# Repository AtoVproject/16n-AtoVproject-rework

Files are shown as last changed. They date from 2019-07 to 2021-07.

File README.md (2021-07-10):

<h1>16n AtoVproject Rework</h1>

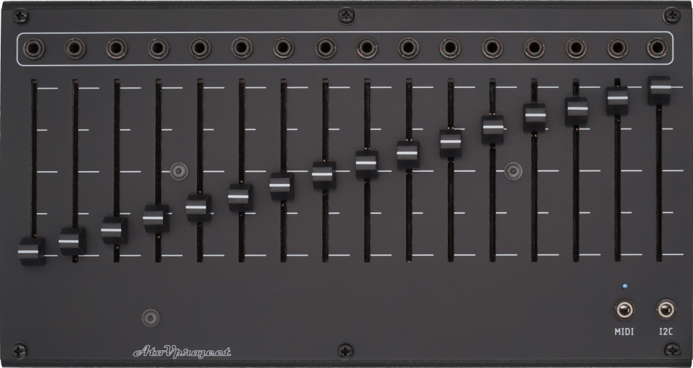
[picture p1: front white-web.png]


Product page: https://atovproject.de/products/16nrework

Manual: https://atovproject.de/manuals/16nrework

This is an hardware modified version of the original 16n. https://github.com/16n-faderbank/16n

Fully assembled unit with high end aluminium enclosure, high end faders and set of cables available @ https://schneidersladen.de/de/atovproject-16n-atovproject-rework

Bourns compatible PCBs Panels and cases are available @ https://pushermanproductions.com/product/16n-euro-version-pcb-and-anodized-aluminium-black-panel/

BOM in the PCB folder

Please download the firmware from the original project https://github.com/16n-faderbank/16n/wiki/Firmware:-installation-instructions

<h2>The concept</h2>

The 16n Faderbank is aimed a solving a problem very specific to modular synthesis. As a patch is getting more and more complex a forest of cables has grown over your system before you know it. The 16n allows you to take the control from the modular into a very ergonomic controller that integrates perfectly into a modern studio.

The 16n is a faderbank sending CV, I2C, MIDI jack compatible with all standards, USB MIDI (compatible PC, Mac, iPad etc...) , making it the absolute ultimate controller for any of your hardware and software all in one! 

This unit was redesigned for a DIY workshop organised in the Berlin Modular community. The redesign was done following the wishes and desires of the community. The 16n AtoVproject redesign is the result of this initiative. 

https://www.youtube.com/watch?v=edriUxDgTsg

<h2>Modifications compared to the original are :</h2>

-Updated power section
  Isolated USB power supply. Proper voltage reference. Upgraded filtering.
    This greatly reduce the noise on the outputs. (Measured at less than 6mV)

-Selectable 5v or 10V outputs: Each can be configured to output either 10V or 5V using a dip switch on the back of the module (even when using 5V USB power supply)

-Outputs facing upwards: The outputs will be directly on the front panel reducing the footprint and making outputs much more accessible.

-Eurorack compatible: You would be able to mount the 16n as a 50hp module in your rack and power it from your own power supply. (+12V=42mA, -12V=0mA)

-The footprint of the jack is compatible for banana connectors! So you'll be able to use it with your Serge or Buchla system.

-I2C connector on the PCB to simplify connection to modules like the ER301

-Two versions of the board are available one with high quality ALPS faders and another one with Bourns mid range faders (1/3 of the price of the ALPS).

<h2>Credits</h2>

Based on original open source work by Brian Crabtree, Sean Hellfritsch, Tom Armitage and Brendon Cassidy. Circuit design update by AtoVproject aka Arthur Gibert

As stated by the original designers the original 16n folows a CC-BY-SA licence therefore the 16n AtoVproject is and will always remain entirely open source following the same licence.

If you are making modification to this design, you must correctly credit everyone involved in the initial version, and also share your own changes with the similar license. So you can’t make a fork of 16n or the 16n AtoVproject redesign that you don’t open-source yourself.

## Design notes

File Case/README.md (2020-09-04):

<h1>Case</h1>

These are files you can send to you laser cutting services (Ponoko, Modulor etc...) to make a case for your Berlin Modular Edition 16n faderbank

I can also cut one for you! Send me an email at info@atovproject.de !

Two version of the case design are available for 3 or 4mm materials. 
This case will work with the 22mm standoffs included in the mouser carts

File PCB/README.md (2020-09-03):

<h1>Gerbers and eagle design files</h1>

Two versions of the board are available. One for high end ALPS faders (which are expensive and quite often out of stock) and another for lower cost Brouns faders (1/3 of the price and more readily available)

The PCB available at https://pushermanproductions.com/product/16n-euro-version-pcb-and-anodized-aluminium-black-panel/ is compatible only with the Brouns faders. 

<h2>Mouser Carts :</h2>

These are complete carts to have all the parts to make the build. They are valid for the latest revision of the boards (v1.4)
Resistors and capacitors are very small so I stronly recommand ordering more (little tip: order resistors and capacitors amounts to the next price break this will make you save a few cents)

Bourns Version
https://www.mouser.com/ProjectManager/ProjectDetail.aspx?AccessID=e279897c7f

ALPS Version
https://www.mouser.com/ProjectManager/ProjectDetail.aspx?AccessID=69297ae739

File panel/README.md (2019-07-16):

<h1>Panel</h1>

The eagle file is a blank template with all the holes and cutouts for the faders and jacks etc... Feel free to create your own design with it

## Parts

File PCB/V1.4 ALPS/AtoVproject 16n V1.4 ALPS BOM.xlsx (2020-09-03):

Qty | Value | Device | Package | Parts | Description | Mouser Number | Note
RESISTOR
2 | 47 | R-EU_R0805 | R0805 | R83, R85 | RESISTOR, European symbol | 603-RT0603FRE0747RL
16 | 1K | R-EU_R0805 | R0805 | R1, R2, R3, R4, R5, R6, R7, R8, R9, R10, R11, R12, R13, R14, R15, R16 | RESISTOR, European symbol | 603-RT0603FRE071KL
32 | 10K | R-EU_R0805 | R0805 | R17, R18, R19, R20, R21, R22, R23, R24, R25, R26, R27, R28, R29, R30, R31, R32, R52, R54, R56, R58, R60, R62, R64, R66, R68, R70, R72, R74, R76, R78, R80, R82 | RESISTOR, European symbol | 603-RT0603FRE0710KL
16 | 10K* | R-EU_R0805 | R0805 | R33, R34, R35, R36, R37, R38, R39, R40, R41, R42, R43, R44, R45, R46, R47, R48 | RESISTOR, European symbol | 603-RT0603FRE0710KL | Can be changed to modify alternative output (eg 10k => 5V, 1.1k => 1V.) Use his formula for desired output R=(100000)/(10-Vout) or use this tool http://www.ohmslawcalculator.com/voltage-divider-calculator
1 | 10k | R-EU_R0805 | R0805 | R84 | RESISTOR, European symbol | 603-RT0603FRE0710KL | Modify to change LED brightness
16 | 20K | R-EU_R0805 | R0805 | R51, R53, R55, R57, R59, R61, R63, R65, R67, R69, R71, R73, R75, R77, R79, R81 | RESISTOR, European symbol | 603-RT0603FRE1320KL
2 | DNP | R-EU_R0805 | R0805 | R49, R50 | RESISTOR, European symbol | 603-RT0603FRE074K7L | Has to be changed to 4.7k to use with ER301
16 | SLIDER | SLIDERS | SLIDEPOT-75 | U$1, U$2, U$3, U$4, U$5, U$6, U$7, U$8, U$9, U$10, U$11, U$12, U$13, U$14, U$15, U$16 | ALPS | 688-RS6011SP6003 | tested with 10k-Value shouldn't matter
CAPACITORS
1 | 10n | C-EUC0805 | C0805 | C3 | CAPACITOR, European symbol | 810-CGA3E2X7R1H103K
9 | 100n | C-EUC0805 | C0805 | C4, C5, C6, C7, C8, C9, C10, C11, C12 | CAPACITOR, European symbol | 810-CGA3E2X7R1H104K
1 | 1u | C-EUC0805 | C0805 | C2 | CAPACITOR, European symbol | 810-CGA3E1X7R1C105AC
1 | 10u | C-EUC0805 | C0805 | C1 | CAPACITOR, European symbol | 810-C1608X6S0G106M
2 | 47uf | CPOL-EUE2.5-6 | E2,5-6 | C100, C101 | POLARIZED CAPACITOR, European symbol | 80-ESS476M025AE2EA | Through hole part Use low profile cap
Diodes - Careful these are polarised
2 | 1N5819W-7-F | DIODE-SOD123 | SOD123 | D1, D6 | DIODE | 621-1N5819HW-F | Reverse voltage protection when using Eurorack power
4 | 1N4148W-7-F | DIODESOD123 | SOD-123 | D2, D3, D4, D5 |  | 621-1N4148W-F | Not needed if not using I2C
1 | LED | LED | LED3MM | LED1 |  | 604-WP710A10SRC/E | Indicate power on state
Ics
4 | MCP6004_SMD | MCP6004_SMD | SO14 | IC5, IC6, IC7, IC8 | Generic Quad Op Amp | 579-MCP6004T-I/SL | Has to be rail to rail op amp
4 | NCS2007 | NCS2007 | SO14 | IC1, IC2, IC3, IC4 |  | 863-NCS20074DR2G | Has to be rail to rail op amp
1 | CD74HC4067SM96 | 744067SO24 | SOIC127P1030X265-24 | IC9 | 16-channel analog MUX | 595-CD74HC4067M
Voltage regulators
1 | DC-ISO | DC-ISO | TMA | V100 | DC/DC Converter TME Series 1 Watt | 709-SPU01L-12 | Converts 5V USB to 12V
1 | EURO_POWER_HEADERREGULAR | EURO_POWER_HEADERREGULAR | EURO_POWER_HEADER | SV100 | Power Header
1 | LM1117 | LM1117 5V | SOT223 | V2 | 5V regulator | 926-LM1117IMPX50NOPB
1 | LP2985 | LP2985 10V | SOT23-5 | V1 | 10V regulator | 595-LP2985-10DBVR
Misc
16 | THONKICONN | THONKICONN | WQP-PJ301M-12JACK-BANANA | J1, J2, J3, J4, J5, J6, J7, J8, J9, J10, J11, J12, J13, J14, J15, J16 | 3.5mm socket for Eurorack modular synths |  | Order at Thonk, Modular Addict, Synthcube etc...
2 | THONKI-STEREO | THONKI-STEREO | WQP-PJ366ST_JACK | JP1, JP2 | 3.5mm socket for Eurorack modular synths |  | Order at Thonk, Modular Addict, Synthcube etc...
2 | 8 position DIP switch | 8 position DIP switch | 8 position DIP switch | S1, S2 |  | 774-2198MST
2 |  | SWITCH-DPDTEG2211 | EG2211 | S100, S101 | Switch | 612-EG2211
1 | TEENSY_3.2_PIN | TEENSY_3.2_PIN | TEENSY_3_AND_LC_SERIES_BOARDS_V1.4_TEENSY_3.0-3.2&LC_DIL | IC10 | Teensy 3.1 or 3.2 in a DIL Layout. | 474-DEV-13736 (https://www.mouser.de/ProductDetail/474-DEV-13736)
 |  |  |  | Standoff 10mm |  | 710-970100321
 |  |  |  | Standoff 22mm |  | 710-970220361
12 |  |  |  | M3 screw
6 |  |  |  | M3 countersunk screw
1 | 40 pin Headers to cu to size |  |  |  |  | 571-41037410

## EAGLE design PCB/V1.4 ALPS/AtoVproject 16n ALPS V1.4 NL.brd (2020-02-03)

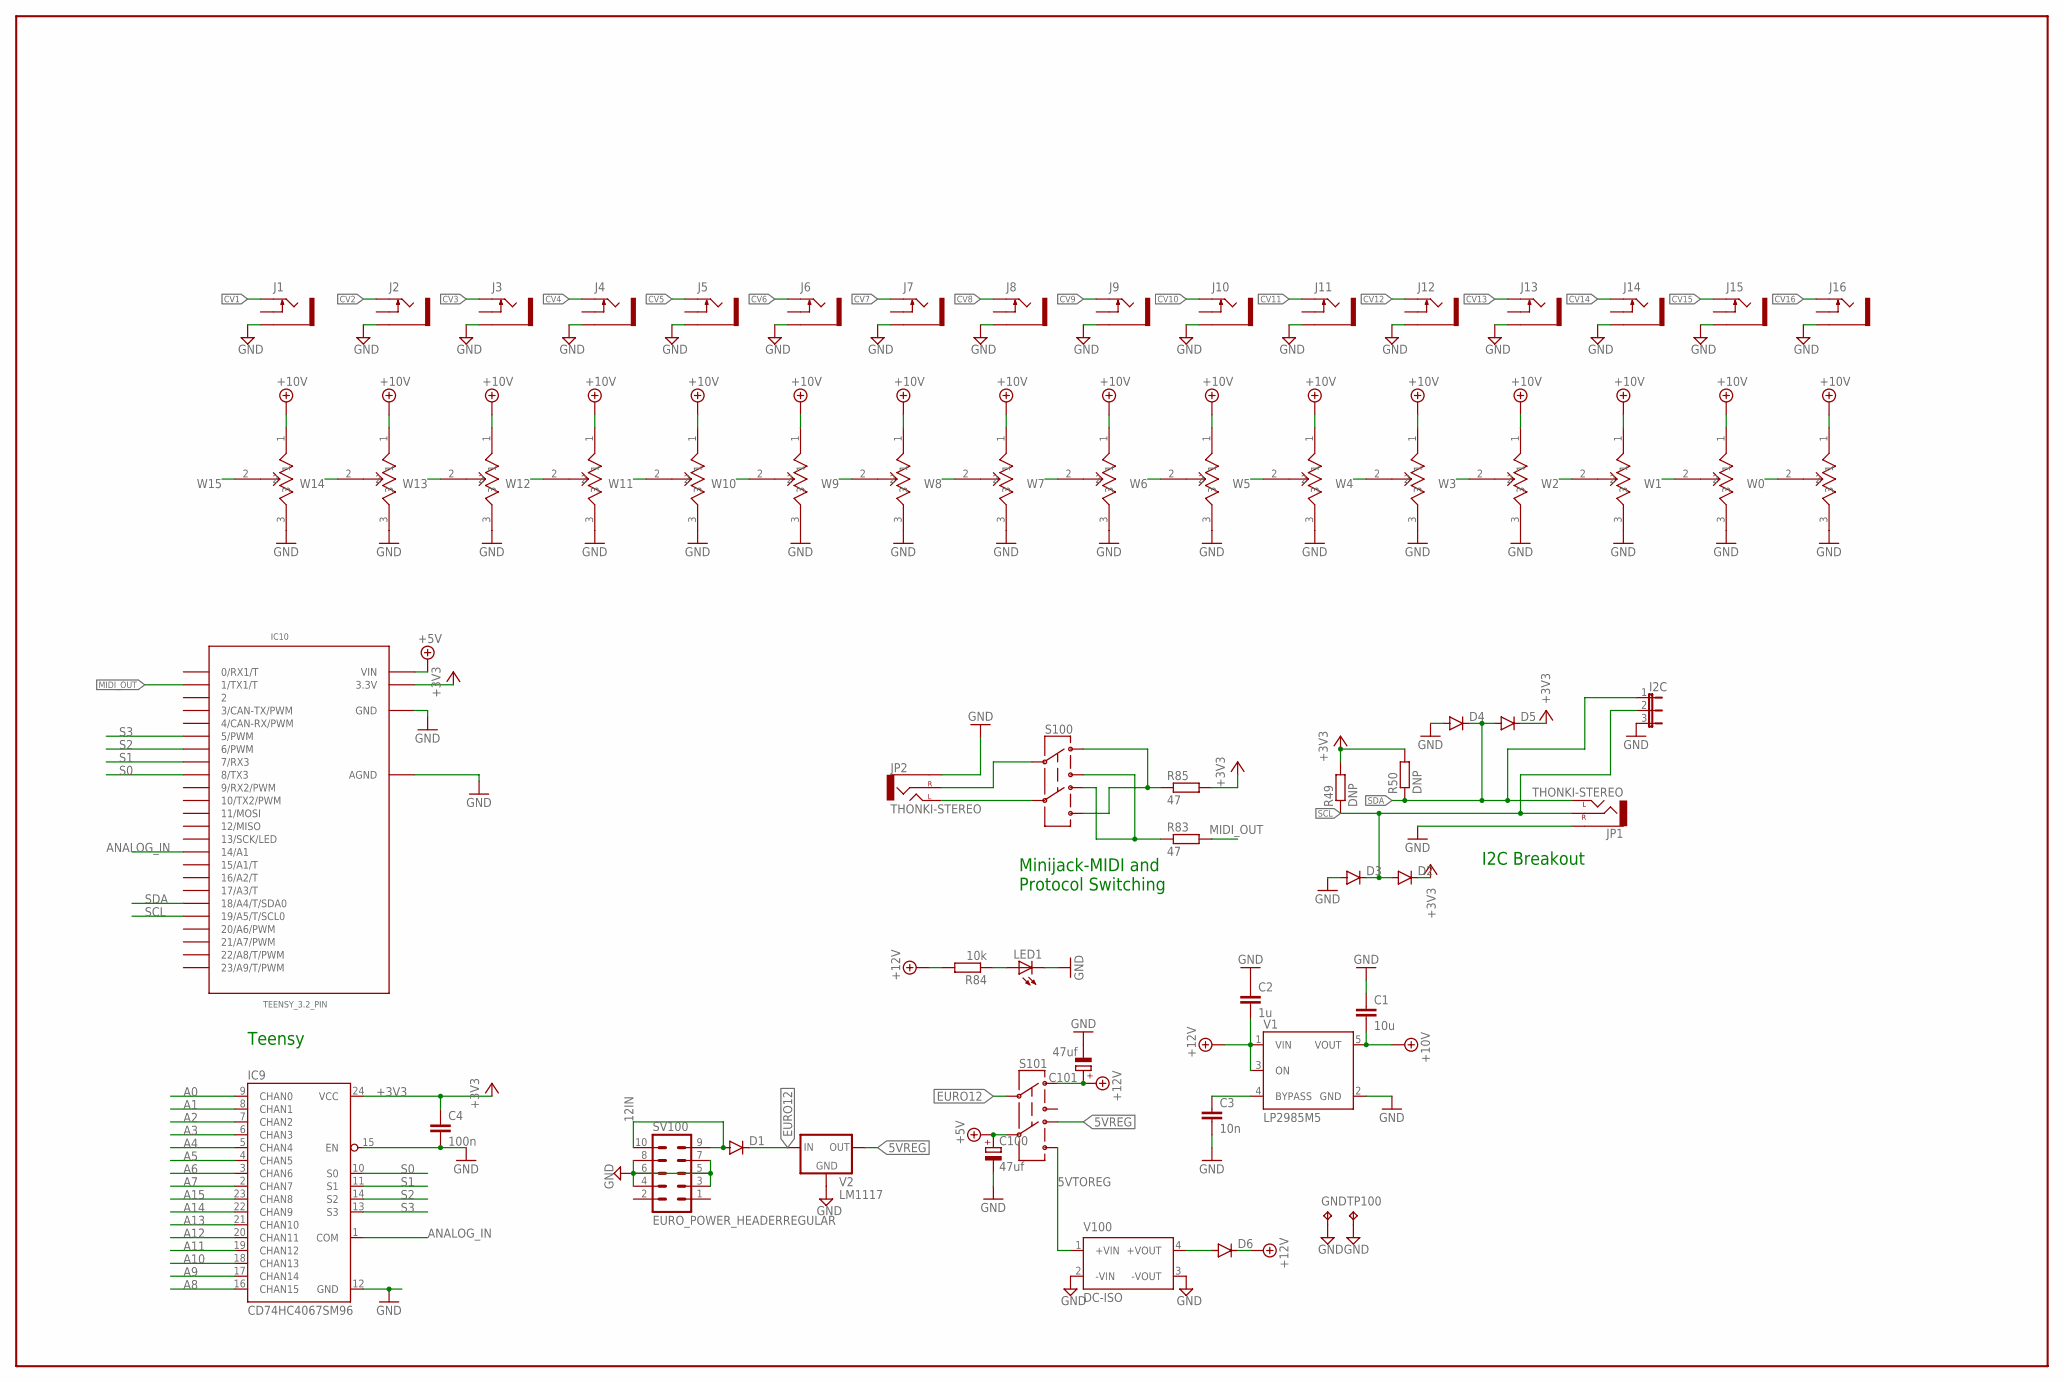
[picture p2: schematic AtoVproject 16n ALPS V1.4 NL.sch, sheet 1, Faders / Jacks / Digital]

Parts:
C1: 10u; C0805
C2: 1u; C0805
C3: 10n; C0805
C4: 100n; C0805
C100, C101: 47uf; E2,5-6
D1, D6: DIODE-SOD123; SOD123
D2, D3, D4, D5: DIODESOD123; SOD-123
GND: TPPAD1-17; P1-17
I2C: JP2E; JP2
IC9: CD74HC4067SM96; SOIC127P1030X265-24
IC10: TEENSY_3.2_PIN; TEENSY_3_AND_LC_SERIES_BOARDS_V1.4_TEENSY_3.0-3.2&LC_DIL
J1, J2, J3, J4, J5, J6, J7, J8, J9, J10, J11, J12, J13, J14, J15, J16: THONKICONN; WQP-PJ301M-12JACK-BANANA
JP1, JP2: THONKI-STEREO; WQP-PJ366ST_JACK
LED1: LED; LED3MM
R49, R50: DNP; R0805
R83, R85: 47; R0805
R84: 10k; R0805
S100, S101: SWITCH-DPDTEG2211; EG2211
SV100: EURO_POWER_HEADERREGULAR; EURO_POWER_HEADER
TP100: TPPAD1-17; P1-17
U$1, U$2, U$3, U$4, U$5, U$6, U$7, U$8, U$9, U$10, U$11, U$12, U$13, U$14, U$15, U$16: SLIDERSALPS-60MM; MONOME_RS6011SP600
V1: LP2985M5; SOT23-5
V2: LM1117; SOT223
V100: DC-ISO; TMA

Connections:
5VREG: S101.P2-TA (4), V2.OUT, V2.TAB (OUT)
5VTOREG: S101.P2-TB (6), V100.1 (+VIN)
12IN: D1.A, SV100.9, SV100.10
+3V3: C4.1, D2.C, D5.C, IC9.24 (VCC), IC10.3.3V, R49.2, R50.2, R85.2
+5V: C100.+, IC10.VIN, S101.P2 (5); also elsewhere on the board
+10V: C1.2, U$1.1, U$2.1, U$3.1, U$4.1, U$5.1, U$6.1, U$7.1, U$8.1, U$9.1, U$10.1, U$11.1, U$12.1, U$13.1, U$14.1, U$15.1, U$16.1, V1.5 (VOUT)
+12V: C2.2, C101.+, D6.C, R84.2, S101.P1-TA (1), V1.1 (VIN), V1.3 (ON); also elsewhere on the board
A0: IC9.9 (CHAN0); also elsewhere on the board
A1: IC9.8 (CHAN1); also elsewhere on the board
A2: IC9.7 (CHAN2); also elsewhere on the board
A3: IC9.6 (CHAN3); also elsewhere on the board
A4: IC9.5 (CHAN4); also elsewhere on the board
A5: IC9.4 (CHAN5); also elsewhere on the board
A6: IC9.3 (CHAN6); also elsewhere on the board
A7: IC9.2 (CHAN7); also elsewhere on the board
A8: IC9.16 (CHAN15); also elsewhere on the board
A9: IC9.17 (CHAN14); also elsewhere on the board
A10: IC9.18 (CHAN13); also elsewhere on the board
A11: IC9.19 (CHAN12); also elsewhere on the board
A12: IC9.20 (CHAN11); also elsewhere on the board
A13: IC9.21 (CHAN10); also elsewhere on the board
A14: IC9.22 (CHAN9); also elsewhere on the board
A15: IC9.23 (CHAN8); also elsewhere on the board
ANALOG_IN: IC9.1 (COM), IC10.14/A0 (14/A1)
CV1: J1.P$1_TIP (TIP); also elsewhere on the board
CV2: J2.P$1_TIP (TIP); also elsewhere on the board
CV3: J3.P$1_TIP (TIP); also elsewhere on the board
CV4: J4.P$1_TIP (TIP); also elsewhere on the board
CV5: J5.P$1_TIP (TIP); also elsewhere on the board
CV6: J6.P$1_TIP (TIP); also elsewhere on the board
CV7: J7.P$1_TIP (TIP); also elsewhere on the board
CV8: J8.P$1_TIP (TIP); also elsewhere on the board
CV9: J9.P$1_TIP (TIP); also elsewhere on the board
CV10: J10.P$1_TIP (TIP); also elsewhere on the board
CV11: J11.P$1_TIP (TIP); also elsewhere on the board
CV12: J12.P$1_TIP (TIP); also elsewhere on the board
CV13: J13.P$1_TIP (TIP); also elsewhere on the board
CV14: J14.P$1_TIP (TIP); also elsewhere on the board
CV15: J15.P$1_TIP (TIP); also elsewhere on the board
CV16: J16.P$1_TIP (TIP); also elsewhere on the board
EURO12: D1.C, S101.P1 (2), V2.IN
GND: C1.1, C2.1, C3.2, C4.2, C100.-, C101.-, D3.A, D4.A, GND.TP, I2C.3, IC9.12 (GND), IC9.15 (EN), IC10.AGND, IC10.GND, J1.P$3_SLEEVE (SLEEVE), J2.P$3_SLEEVE (SLEEVE), J3.P$3_SLEEVE (SLEEVE), J4.P$3_SLEEVE (SLEEVE), J5.P$3_SLEEVE (SLEEVE), J6.P$3_SLEEVE (SLEEVE), J7.P$3_SLEEVE (SLEEVE), J8.P$3_SLEEVE (SLEEVE), J9.P$3_SLEEVE (SLEEVE), J10.P$3_SLEEVE (SLEEVE), J11.P$3_SLEEVE (SLEEVE), J12.P$3_SLEEVE (SLEEVE), J13.P$3_SLEEVE (SLEEVE), J14.P$3_SLEEVE (SLEEVE), J15.P$3_SLEEVE (SLEEVE), J16.P$3_SLEEVE (SLEEVE), JP1.P$3_SLEEVE (SLEEVE), JP2.P$3_SLEEVE (SLEEVE), LED1.K (C), SV100.3, SV100.4, SV100.5, SV100.6, SV100.7, SV100.8, TP100.TP, U$1.3, U$2.3, U$3.3, U$4.3, U$5.3, U$6.3, U$7.3, U$8.3, U$9.3, U$10.3, U$11.3, U$12.3, U$13.3, U$14.3, U$15.3, U$16.3, V1.2 (GND), V2.GND, V100.2 (-VIN), V100.3 (-VOUT); also elsewhere on the board
MIDI_OUT: IC10.1 (1/TX1/T), R83.2
unnamed: JP2.P$1_TIP (LEFT), S100.P2 (5)
unnamed: JP2.P$2_SWITCH (RIGHT), S100.P1 (2)
unnamed: R83.1, S100.P1-TB (3), S100.P2-TA (4)
unnamed: R85.1, S100.P1-TA (1), S100.P2-TB (6)
unnamed: LED1.A, R84.1
unnamed: D6.A, V100.4 (+VOUT)
unnamed: C3.1, V1.4 (BYPASS)
S0: IC9.10 (S0), IC10.8 (8/TX3)
S1: IC9.11 (S1), IC10.7 (7/RX3)
S2: IC9.14 (S2), IC10.6 (6/PWM)
S3: IC9.13 (S3), IC10.5 (5/PWM)
SCL: D2.A, D3.C, I2C.2, IC10.19/A5 (19/A5/T/SCL0), JP1.P$2_SWITCH (RIGHT), R49.1
SDA: D4.C, D5.A, I2C.1, IC10.18/A4 (18/A4/T/SDA0), JP1.P$1_TIP (LEFT), R50.1
W0: U$1.2; also elsewhere on the board
W1: U$2.2; also elsewhere on the board
W2: U$3.2; also elsewhere on the board
W3: U$4.2; also elsewhere on the board
W4: U$5.2; also elsewhere on the board
W5: U$6.2; also elsewhere on the board
W6: U$7.2; also elsewhere on the board
W7: U$8.2; also elsewhere on the board
W8: U$9.2; also elsewhere on the board
W9: U$10.2; also elsewhere on the board
W10: U$11.2; also elsewhere on the board
W11: U$12.2; also elsewhere on the board
W12: U$13.2; also elsewhere on the board
W13: U$14.2; also elsewhere on the board
W14: U$15.2; also elsewhere on the board
W15: U$16.2; also elsewhere on the board

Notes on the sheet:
Teensy
I2C Breakout
Minijack-MIDI and Protocol Switching

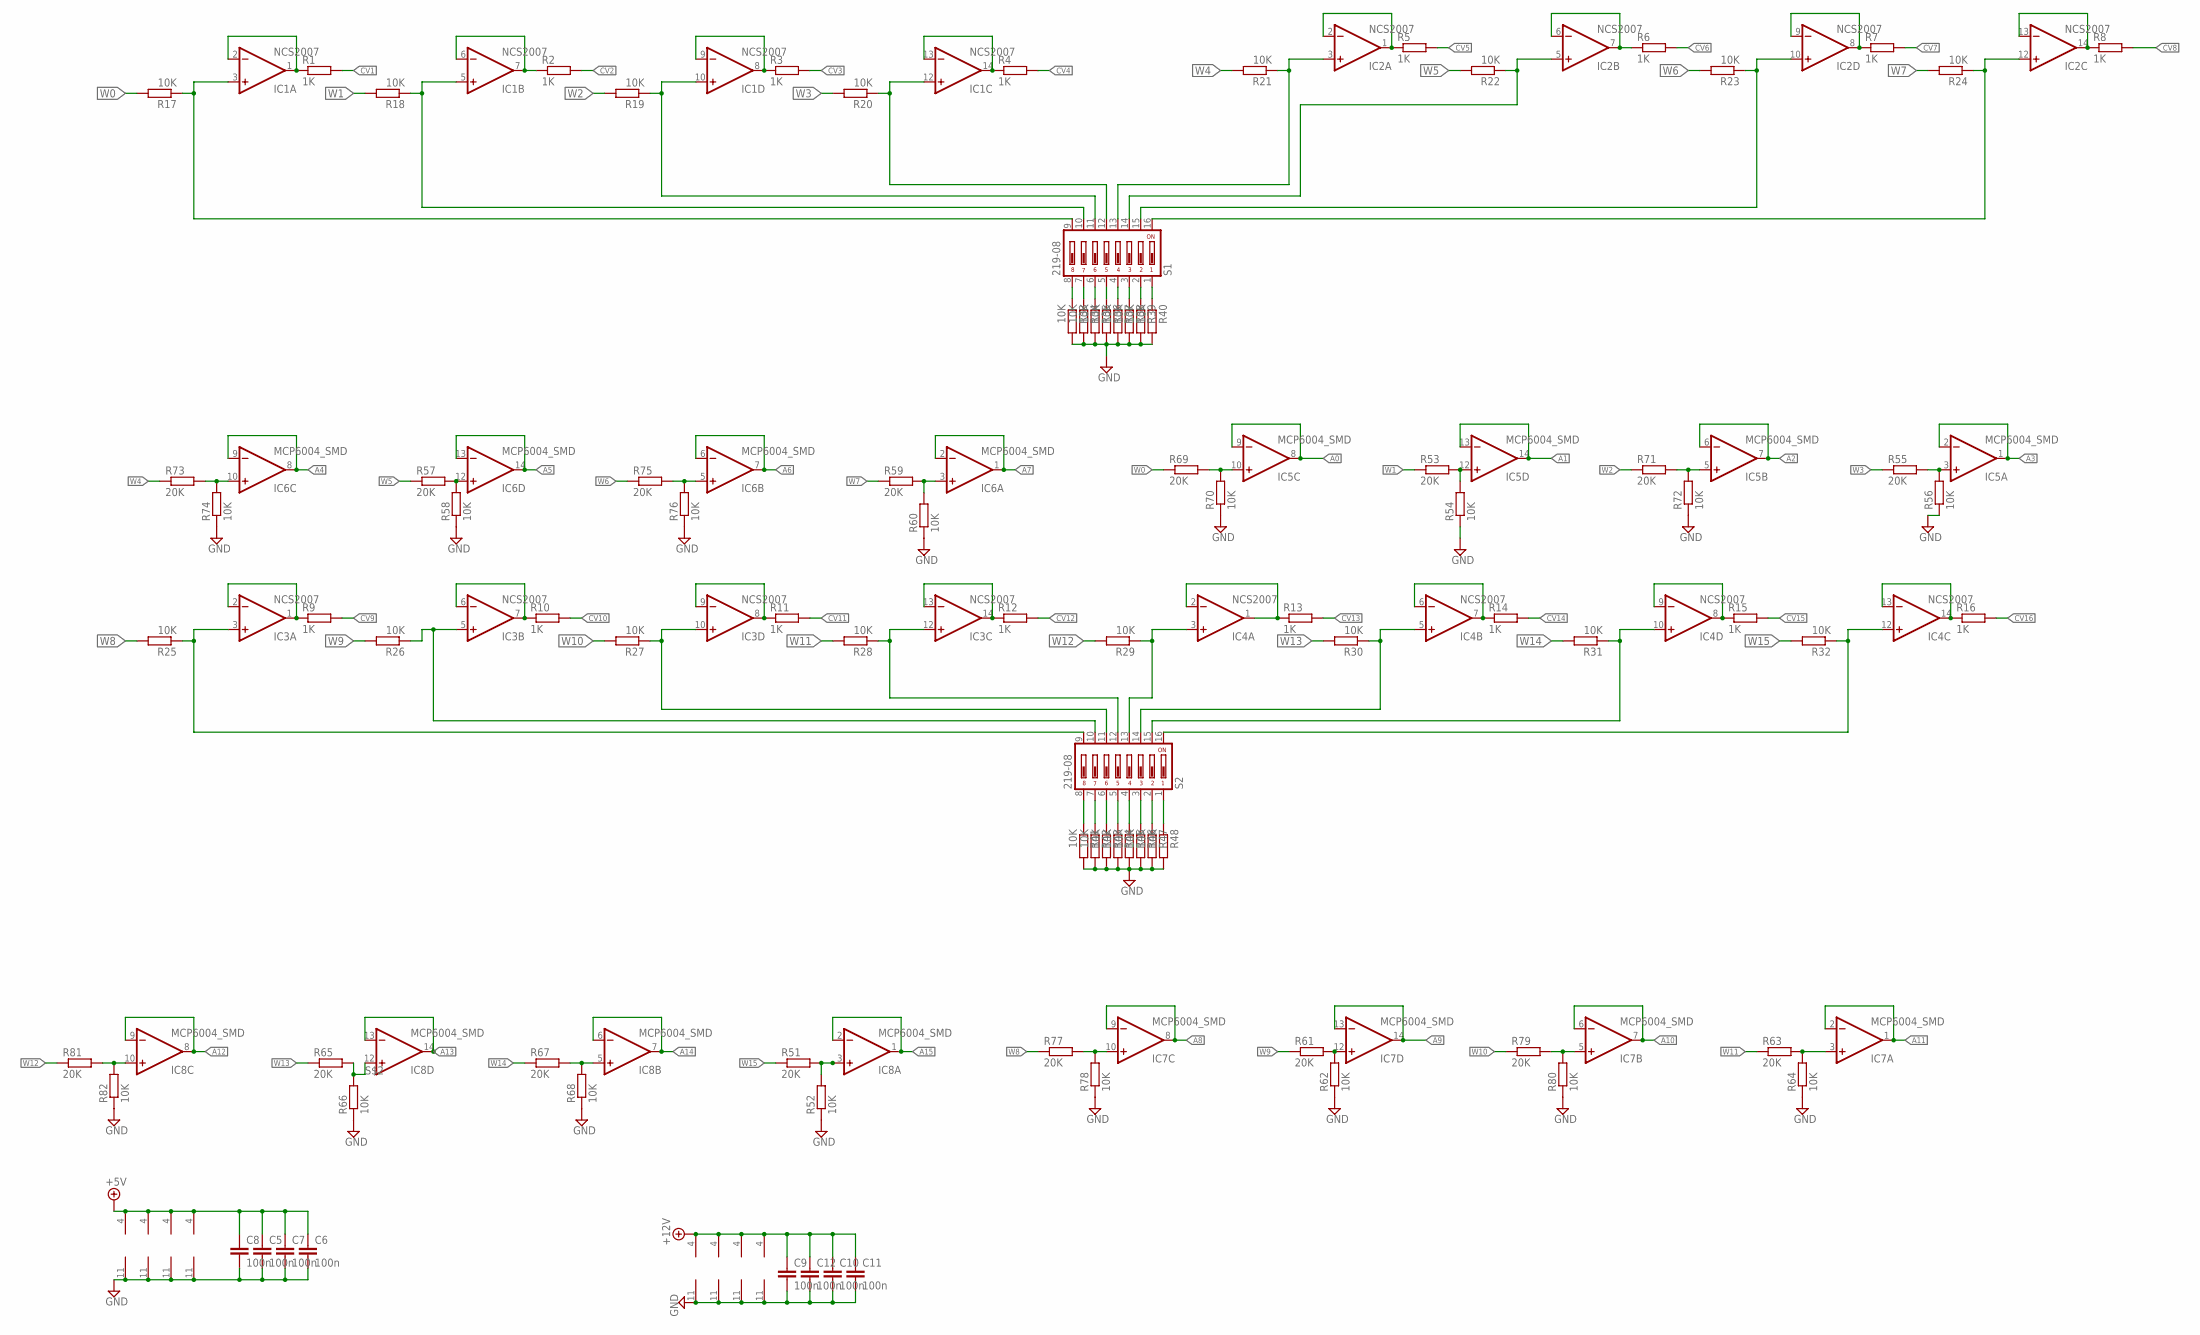
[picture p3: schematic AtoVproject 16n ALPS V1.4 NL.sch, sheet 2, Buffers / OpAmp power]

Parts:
C5, C6, C7, C8, C9, C10, C11, C12: 100n; C0805
IC1, IC2, IC3, IC4: NCS2007; SO14
IC5, IC6, IC7, IC8: MCP6004_SMD; SO14
R1, R2, R3, R4, R5, R6, R7, R8, R9, R10, R11, R12, R13, R14, R15, R16: 1K; R0805
R17, R18, R19, R20, R21, R22, R23, R24, R25, R26, R27, R28, R29, R30, R31, R32, R33, R34, R35, R36, R37, R38, R39, R40, R41, R42, R43, R44, R45, R46, R47, R48, R52, R54, R56, R58, R60, R62, R64, R66, R68, R70, R72, R74, R76, R78, R80, R82: 10K; R0805
R51, R53, R55, R57, R59, R61, R63, R65, R67, R69, R71, R73, R75, R77, R79, R81: 20K; R0805
S1, S2: 219-08; CTS-219-08

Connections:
+5V: C5.1, C6.1, C7.1, C8.1, IC5.4 (V+), IC6.4 (V+), IC7.4 (V+), IC8.4 (V+); also elsewhere on the board
+12V: C9.1, C10.1, C11.1, C12.1, IC1.4 (V+), IC2.4 (V+), IC3.4 (V+), IC4.4 (V+); also elsewhere on the board
A0: IC5.8 (OUT), IC5.9 (-IN); also elsewhere on the board
A1: IC5.13 (-IN), IC5.14 (OUT); also elsewhere on the board
A2: IC5.6 (-IN), IC5.7 (OUT); also elsewhere on the board
A3: IC5.1 (OUT), IC5.2 (-IN); also elsewhere on the board
A4: IC6.8 (OUT), IC6.9 (-IN); also elsewhere on the board
A5: IC6.13 (-IN), IC6.14 (OUT); also elsewhere on the board
A6: IC6.6 (-IN), IC6.7 (OUT); also elsewhere on the board
A7: IC6.1 (OUT), IC6.2 (-IN); also elsewhere on the board
A8: IC7.8 (OUT), IC7.9 (-IN); also elsewhere on the board
A9: IC7.13 (-IN), IC7.14 (OUT); also elsewhere on the board
A10: IC7.6 (-IN), IC7.7 (OUT); also elsewhere on the board
A11: IC7.1 (OUT), IC7.2 (-IN); also elsewhere on the board
A12: IC8.8 (OUT), IC8.9 (-IN); also elsewhere on the board
A13: IC8.13 (-IN), IC8.14 (OUT); also elsewhere on the board
A14: IC8.6 (-IN), IC8.7 (OUT); also elsewhere on the board
A15: IC8.1 (OUT), IC8.2 (-IN); also elsewhere on the board
CV1: R1.2; also elsewhere on the board
CV2: R2.2; also elsewhere on the board
CV3: R3.2; also elsewhere on the board
CV4: R4.2; also elsewhere on the board
CV5: R5.2; also elsewhere on the board
CV6: R6.2; also elsewhere on the board
CV7: R7.2; also elsewhere on the board
CV8: R8.2; also elsewhere on the board
CV9: R9.2; also elsewhere on the board
CV10: R10.2; also elsewhere on the board
CV11: R11.2; also elsewhere on the board
CV12: R12.2; also elsewhere on the board
CV13: R13.2; also elsewhere on the board
CV14: R14.2; also elsewhere on the board
CV15: R15.2; also elsewhere on the board
CV16: R16.2; also elsewhere on the board
GND: C5.2, C6.2, C7.2, C8.2, C9.2, C10.2, C11.2, C12.2, IC1.11 (V-), IC2.11 (V-), IC3.11 (V-), IC4.11 (V-), IC5.11 (V-), IC6.11 (V-), IC7.11 (V-), IC8.11 (V-), R33.2, R34.2, R35.2, R36.2, R37.2, R38.2, R39.2, R40.2, R41.2, R42.2, R43.2, R44.2, R45.2, R46.2, R47.2, R48.2, R52.1, R54.1, R56.1, R58.1, R60.1, R62.1, R64.1, R66.1, R68.1, R70.1, R72.1, R74.1, R76.1, R78.1, R80.1, R82.1; also elsewhere on the board
unnamed: IC1.3 (+IN), R17.1, S1.9
unnamed: IC5.5 (+IN), R71.2, R72.2
unnamed: IC5.3 (+IN), R55.2, R56.2
unnamed: R33.1, S1.8
unnamed: IC5.10 (+IN), R69.2, R70.2
unnamed: IC5.12 (+IN), R53.2, R54.2
unnamed: IC1.5 (+IN), R18.1, S1.10
unnamed: IC6.10 (+IN), R73.2, R74.2
unnamed: IC6.12 (+IN), R57.2, R58.2
unnamed: R34.1, S1.7
unnamed: IC6.5 (+IN), R75.2, R76.2
unnamed: IC6.3 (+IN), R59.2, R60.2
unnamed: IC1.10 (+IN), R19.1, S1.11
unnamed: IC7.10 (+IN), R77.2, R78.2
unnamed: IC7.12 (+IN), R61.2, R62.2
unnamed: R35.1, S1.6
unnamed: IC7.5 (+IN), R79.2, R80.2
unnamed: IC7.3 (+IN), R63.2, R64.2
unnamed: IC1.12 (+IN), R20.1, S1.12
unnamed: IC8.3 (+IN), R51.2, R52.2
unnamed: IC8.10 (+IN), R81.2, R82.2
unnamed: R36.1, S1.5
unnamed: IC8.5 (+IN), R67.2, R68.2
unnamed: IC2.3 (+IN), R21.1, S1.13
unnamed: R37.1, S1.4
unnamed: IC2.5 (+IN), R22.1, S1.14
unnamed: R38.1, S1.3
unnamed: IC2.10 (+IN), R23.1, S1.15
unnamed: R39.1, S1.2
unnamed: IC2.12 (+IN), R24.1, S1.16
unnamed: R40.1, S1.1
unnamed: IC3.3 (+IN), R25.1, S2.9
unnamed: R41.1, S2.8
unnamed: IC3.5 (+IN), R26.1, S2.10
unnamed: R42.1, S2.7
unnamed: IC3.10 (+IN), R27.1, S2.11
unnamed: R43.1, S2.6
unnamed: IC3.12 (+IN), R28.1, S2.12
unnamed: R44.1, S2.5
unnamed: IC4.3 (+IN), R29.1, S2.13
unnamed: R45.1, S2.4
unnamed: IC4.5 (+IN), R30.1, S2.14
unnamed: R46.1, S2.3
unnamed: IC4.10 (+IN), R31.1, S2.15
unnamed: R47.1, S2.2
unnamed: IC4.12 (+IN), R32.1, S2.16
unnamed: R48.1, S2.1
unnamed: IC4.8 (OUT), IC4.9 (-IN), R15.1
unnamed: IC1.1 (OUT), IC1.2 (-IN), R1.1
unnamed: IC1.6 (-IN), IC1.7 (OUT), R2.1
unnamed: IC1.8 (OUT), IC1.9 (-IN), R3.1
unnamed: IC1.13 (-IN), IC1.14 (OUT), R4.1
unnamed: IC2.1 (OUT), IC2.2 (-IN), R5.1
unnamed: IC2.6 (-IN), IC2.7 (OUT), R6.1
unnamed: IC2.8 (OUT), IC2.9 (-IN), R7.1
unnamed: IC2.13 (-IN), IC2.14 (OUT), R8.1
unnamed: IC3.1 (OUT), IC3.2 (-IN), R9.1
unnamed: IC3.6 (-IN), IC3.7 (OUT), R10.1
unnamed: IC3.8 (OUT), IC3.9 (-IN), R11.1
unnamed: IC3.13 (-IN), IC3.14 (OUT), R12.1
unnamed: IC4.1 (OUT), IC4.2 (-IN), R13.1
unnamed: IC4.6 (-IN), IC4.7 (OUT), R14.1
unnamed: IC4.13 (-IN), IC4.14 (OUT), R16.1
S$2: IC8.12 (+IN), R65.2, R66.2
W0: R17.2, R69.1; also elsewhere on the board
W1: R18.2, R53.1; also elsewhere on the board
W2: R19.2, R71.1; also elsewhere on the board
W3: R20.2, R55.1; also elsewhere on the board
W4: R21.2, R73.1; also elsewhere on the board
W5: R22.2, R57.1; also elsewhere on the board
W6: R23.2, R75.1; also elsewhere on the board
W7: R24.2, R59.1; also elsewhere on the board
W8: R25.2, R77.1; also elsewhere on the board
W9: R26.2, R61.1; also elsewhere on the board
W10: R27.2, R79.1; also elsewhere on the board
W11: R28.2, R63.1; also elsewhere on the board
W12: R29.2, R81.1; also elsewhere on the board
W13: R30.2, R65.1; also elsewhere on the board
W14: R31.2, R67.1; also elsewhere on the board
W15: R32.2, R51.1; also elsewhere on the board

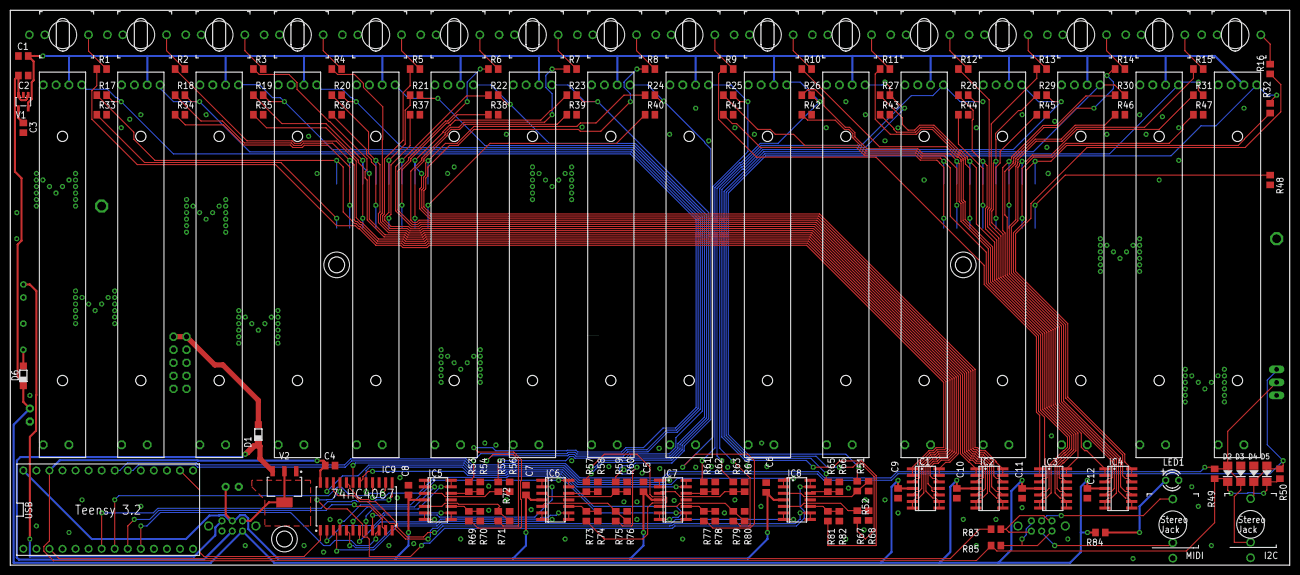
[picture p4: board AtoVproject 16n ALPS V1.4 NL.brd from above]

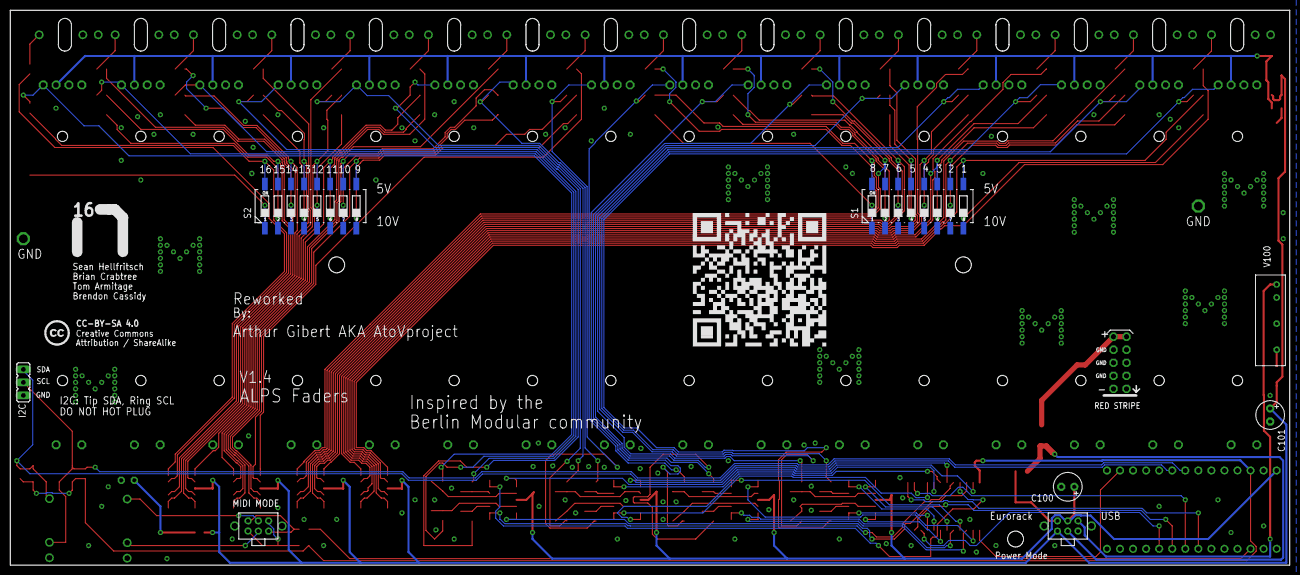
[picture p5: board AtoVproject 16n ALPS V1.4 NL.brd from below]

Board: 2 copper layers, 248.9 x 108.0 mm, 161 parts (11 on the bottom side), 136 nets.

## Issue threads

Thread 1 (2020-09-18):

midi switch settings

oldmanfury, 2020-09-18:
Can you put some text in the description about how the midi switch is set up?  The original board had K and A written on it for the two swtich positions - Korg and Arturia Beatstep, i.e. MIDI A and MIDI B.  Which position is which?  One of the positions has hash marks under it - is that MIDI A / Korg?

AtoVproject, 2020-09-22:
Hi,

The positions are described in the user manual.
[https://atovproject.de/manuals/16nrework](https://atovproject.de/manuals/16nrework)

"If the device you want to control follows the type A mini-jack MIDI standard, set the switch to the left. If the device you want to control follows the type B mini-jack MIDI standard, set the switch to the right"

Cheers

oldmanfury, 2020-09-22:
Wow... can't believe I missed the manual.  Beautifully written BTW.  Sorry about that

AtoVproject, 2020-09-28:
You didn't miss anything, I just put it online a few days ago!

Closed 2020-12-05.

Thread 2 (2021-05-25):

Update to 1.5?

MacTuitui, 2021-05-25:
Hi and thanks for the amazing project.

I'm trying to get familiar with the whole process of designing a board, ordering it online (including assembly of smd parts) then finishing the build by manually soldering the bigger parts, looking to replicate this project, and if I ever find a way to improve it (hardware or firmware) I would gladly contribute the changes back.

Very tiny nitpick though is that the kits seem to be at version 1.5 yet the files here still show 1.4. Is there any significant difference between the two? Would you mind if possible publishing the 1.5 version?

Thanks in advance!

AtoVproject, 2021-07-10:
The V1.5 is our inhouse production version.

The schematic remains the same. The difference are in package size of some parts and the silkscreen. The 1.4 is more DIY friendly and will therefore remain the version shared on github.

Feel free to produce your own version! Don't forget to share the improvements you made with the same license CC-BY-SA

Cheers

Closed 2021-07-10.

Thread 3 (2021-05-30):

Standoff holes on the pcb do not match the panel files

rahji, 2021-05-30:
The two standoff holes near the vertical center of the pcb do not match the holes in the panel. Note that the bottom standoff hole is in the right place (as are the holes for the jacks). It's just the two other standoff holes that are misplaced. I found this out after having boards made using the Eagle files in the repo and getting a panel from someone who used the files in the repo. The holes in the panel had to be redrilled to match (since there is a trace too close to the hole in the pcb to widen that hole). The image below overlays the PCB and the front panel BRD files...

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

AtoVproject, 2021-07-10:
Thanks for raising this up! This is now fixed

rahji, 2021-07-10:
Do you mean you fixed this for the 1.4 version that's here? (Independent of the 1.5 version that will end up here at some point)

AtoVproject, 2021-07-10:
I've fixed the file that was already online.

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

Closed 2021-07-10.

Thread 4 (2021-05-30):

Case holes are in the wrong place

rahji, 2021-05-30:
The 4 corner holes for the case files are in the wrong place. The image below overlays the pcb, the front panel, and the DXF for the laser cut case. The little grey ticks are the hole positions for the case - you can see how they don't line up with the front panel slots.
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.
 I found this after laser cutting using the SVG file. All parts fit together well, but the mounting holes are misplaced. This problem is independent of the material thickness - the problem is that the holes do not line up with the front panel holes (which are based on Eurorack standards).

rahji, 2021-05-30:
A corrected Adobe Illustrator file...

[16n box 3mm fixed holes AI.zip](https://github.com/AtoVproject/16n-AtoVproject-rework/files/6566877/16n.box.3mm.fixed.holes.AI.zip)

AtoVproject, 2021-07-10:
Thanks for the sharing the file, tt is now shared

Closed 2021-07-10.

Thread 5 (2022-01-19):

Enhancement Request.

jpnielsen, 2022-01-19:
Please make it possible to output 14-bit midi over USB.

CC / CC+ 32 fashion is OK

I found an example here: https://madskjeldgaard.dk/posts/14bit-midi-teensy-supercollider/

I don't need [NRPN](https://en.wikipedia.org/wiki/NRPN), only the "fine adjustment" allready in the conventional MIDI controller specification, where any of the first 32 controls can be optionally paired with a control offset 32 higher.

It could just use fixed CC's {0,1,2,3,4,5,6,7,8,9,10,11,12,13,14,15} and {32,33,34,35,36,37,38,39,40,41,42,43,44,45,46,47} - that's all I need.

I could probably make the hack myself - but would prefer it being part of the official firmware.

Cheers,
Jens Peter

PS: I bought the kit from Exploding Shed last week - Is it possible to buy only the case + a blank front panel with just the six mounting holes? I would like to build another box like the 16n-AtoVproject-rework, with 2 joysticks and some buttons.

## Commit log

2019-07-16 Rename panel/Eagle/AtoVproject 16n Panel blank.brd to panel/Eagle/v1.1/AtoVproject 16n Panel blank.brd
    [AtoVproject 16n Panel blank.brd]
2019-07-16 Rename panel/Eagle/v1.1/AtoVproject 16n Panel blank.brd to panel/Eagle/AtoVproject 16n Panel blank.brd
    [AtoVproject 16n Panel blank.brd]
2019-07-16 Rename AtoVproject 16n ALPS V1.2NL.brd to PCB/AtoVproject 16n ALPS V1.2NL.brd
    [AtoVproject 16n ALPS V1.2NL.brd]
2019-07-16 Rename AtoVproject 16n BOURNS V1.2NL.brd to PCB/AtoVproject 16n BOURNS V1.2NL.brd
    [AtoVproject 16n BOURNS V1.2NL.brd]
2019-07-16 Rename panel/Eagle/AtoVproject 16n Panel blank.brd to panel/AtoVproject 16n Panel blank.brd
    [AtoVproject 16n Panel blank.brd]
2019-07-16 Modified firmware to work with ER301
    -Delay in teensy setup to wait for ER301 to start before initiating i2c conection
    -i2c as master
2019-12-17 case update
    [16n Case 3mm.dxf, 16n Case 4mm.dxf, 16n box 4mm.dxf]
2020-02-03 Fix C1 Value in eagle files
    [AtoVproject 16n Bourns V1.4 NL.brd, AtoVproject 16n Bourns V1.4 NL.sch]
2020-02-03 typo fixed, C1 Value Eagle, Add ALPS files
    [AtoVproject 16n ALPS V1.4 NL.brd, AtoVproject 16n ALPS V1.4 NL.sch, AtoVproject 16n V1.4 ALPS BOM.xlsx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]
2020-09-03 Removed firmware
    [AtoVproject 16n V1.4 ALPS BOM.xlsx]
2021-07-10 Panel hole fixed
2021-07-10 Case and panel hole fixed
    [16n box 3mm.dxf, 16n box 4mm.dxf]

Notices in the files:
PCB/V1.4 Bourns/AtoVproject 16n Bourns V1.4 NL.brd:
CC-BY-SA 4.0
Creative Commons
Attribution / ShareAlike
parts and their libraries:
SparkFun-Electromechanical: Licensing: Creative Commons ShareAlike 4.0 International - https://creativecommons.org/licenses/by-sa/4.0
